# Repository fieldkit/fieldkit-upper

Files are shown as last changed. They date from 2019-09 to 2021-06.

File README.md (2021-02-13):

# FieldKit-*Upper*
The Upper board constitutes the thinky bits of the FieldKit system.
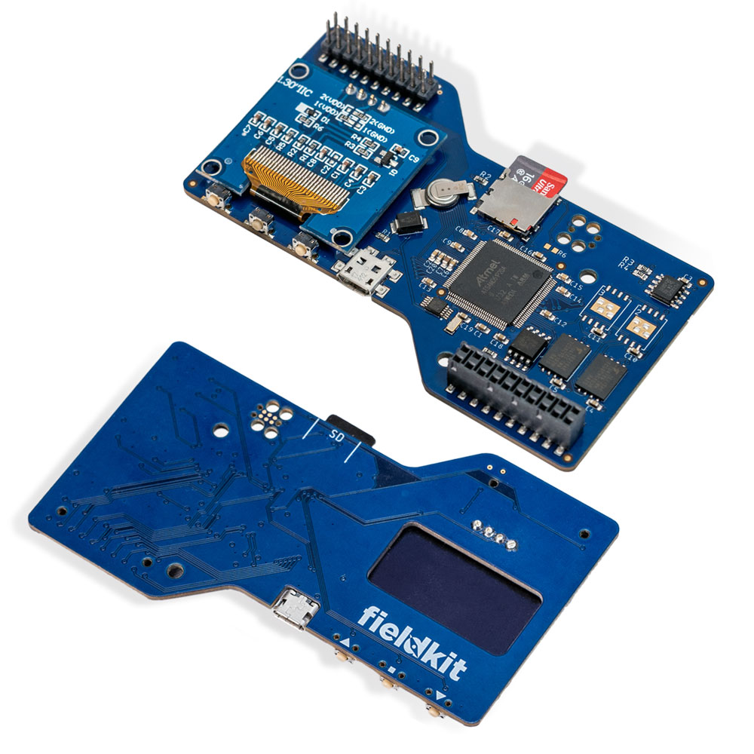
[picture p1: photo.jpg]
Photograph of Fieldkit Board


## Architecture
Every Fieldkit has at least three boards: Upper, Lower, and Module Base. Upper contains :

- The microcontroller.
- The OLED display and buttons.
- The real-time clock and its backup power supply.
- Flash memory for firmware.
- Separate NAND flash for data storage.
- The Micro-SD Card Slot.
- The USB Port.
- A temperature sensor.

## License Information

> *"In the long history of humankind (and animal kind, too) those who learned to collaborate and improvise most effectively have prevailed."*
>  --**Charles Darwin**

This hardware is released under **CERN Open Hardware License Version 2 - Permissive (CERN-OHL_P)**
Obviously, it's Distributed as-is; and no warranty is given.

---
*Upper was Designed by Bradley Gawthrop for FieldKit.*

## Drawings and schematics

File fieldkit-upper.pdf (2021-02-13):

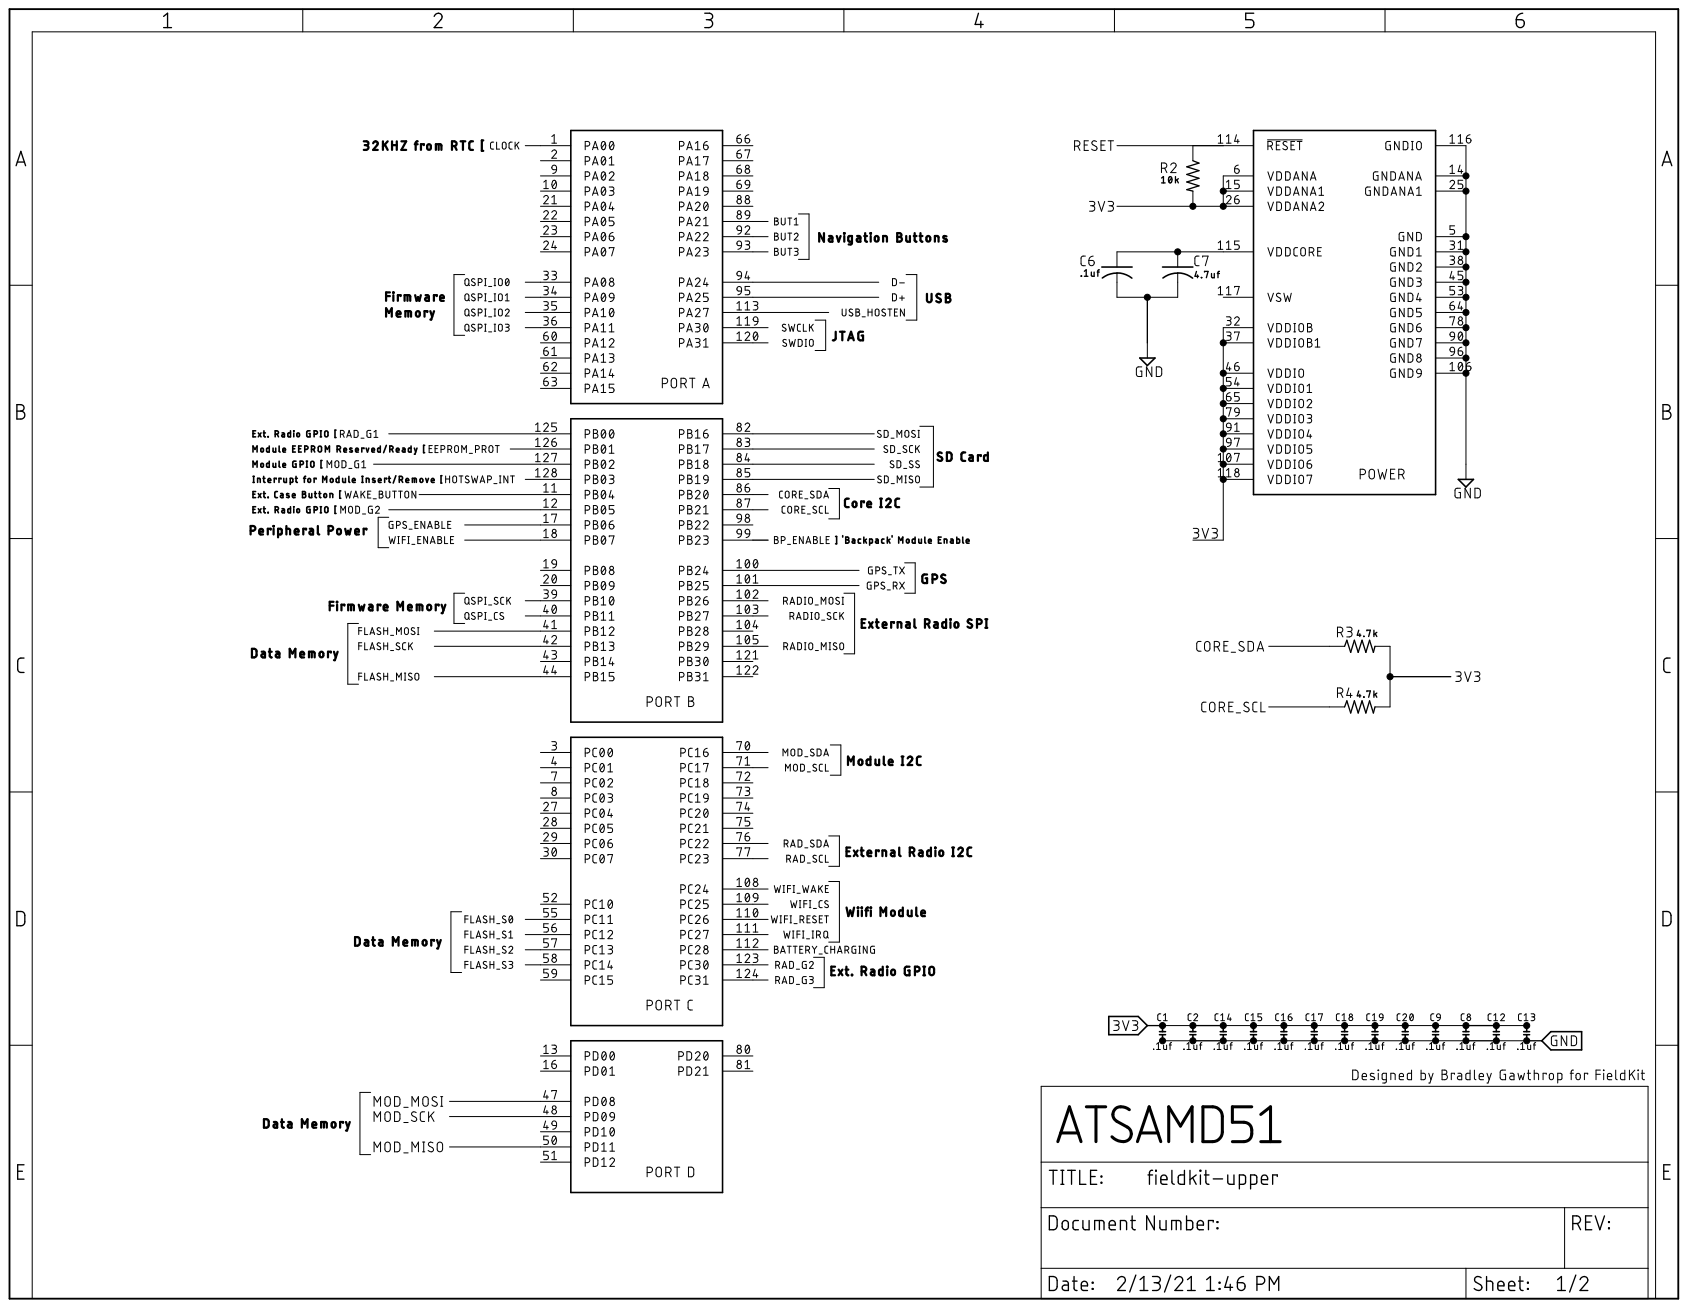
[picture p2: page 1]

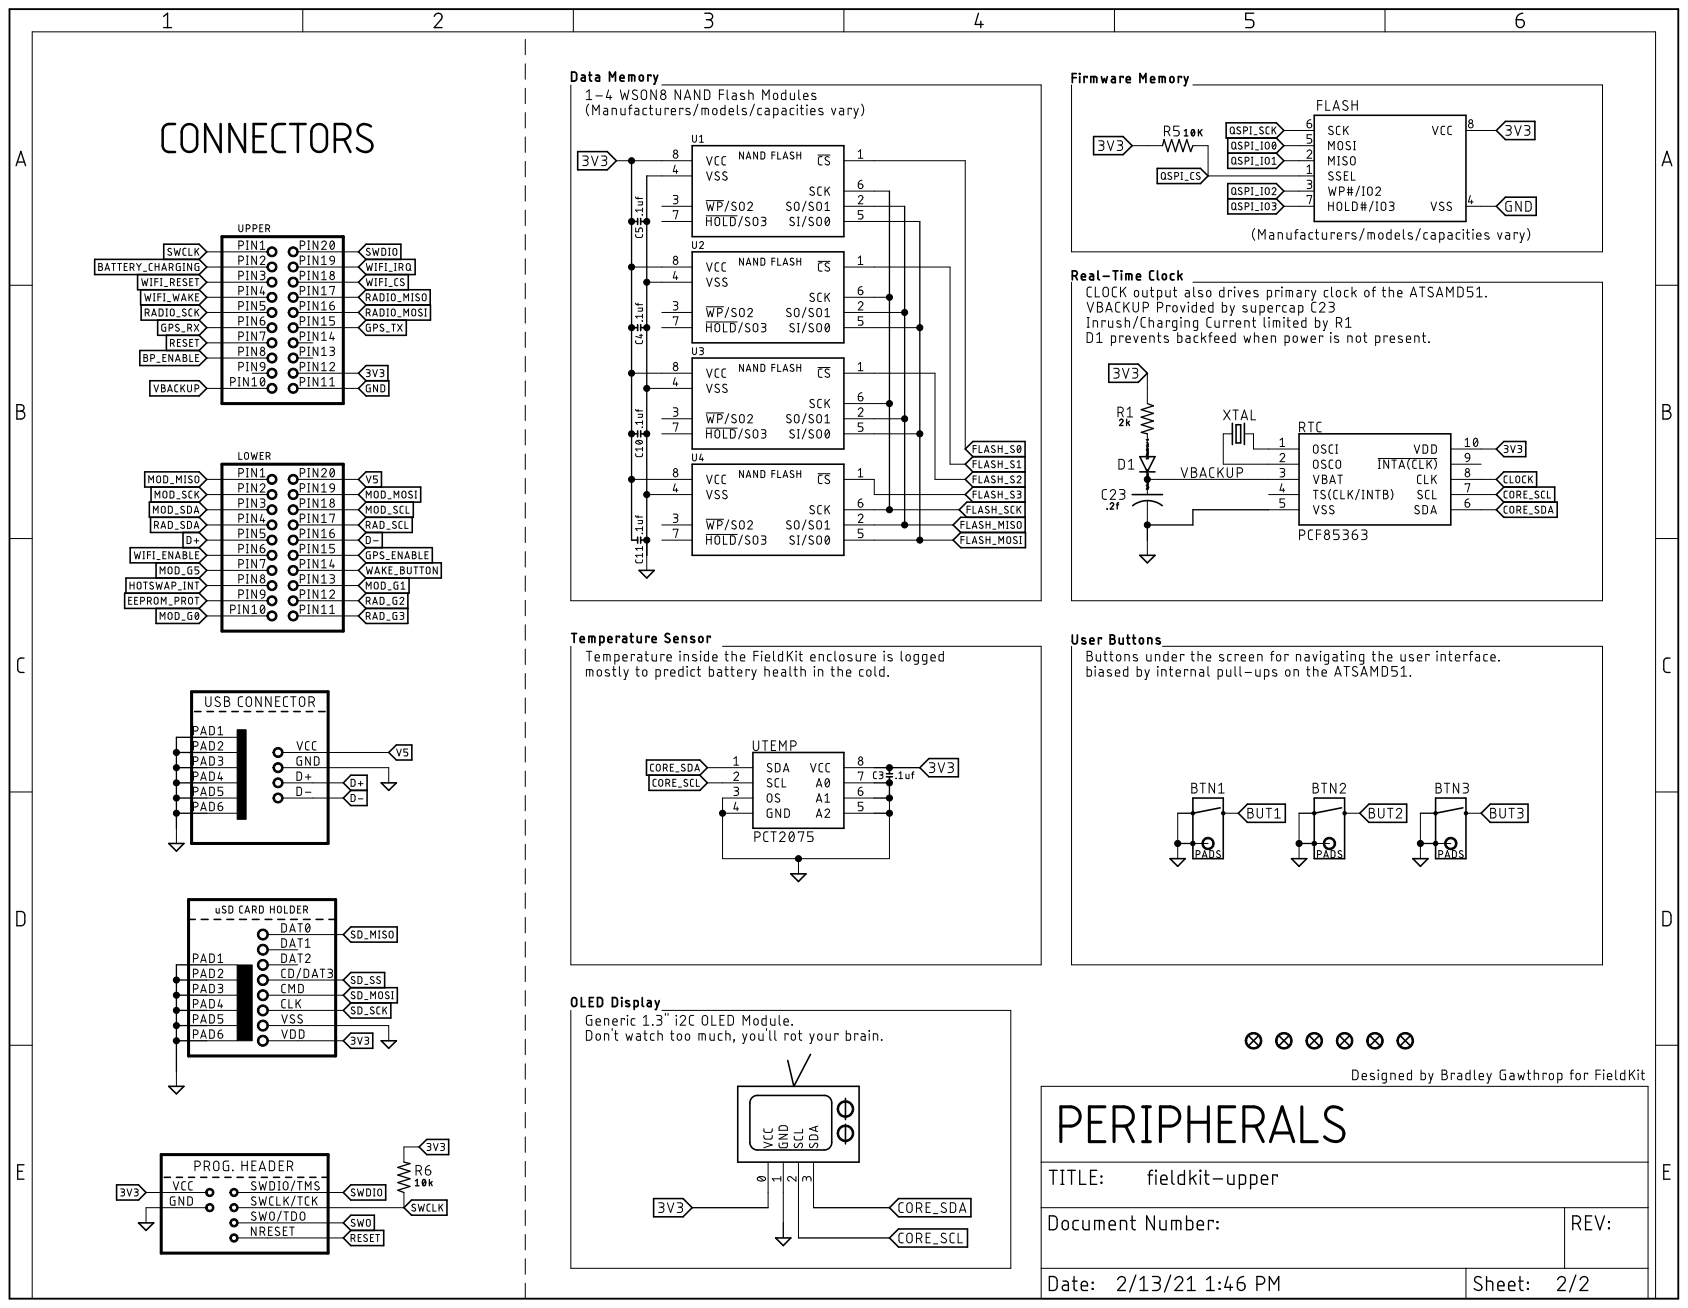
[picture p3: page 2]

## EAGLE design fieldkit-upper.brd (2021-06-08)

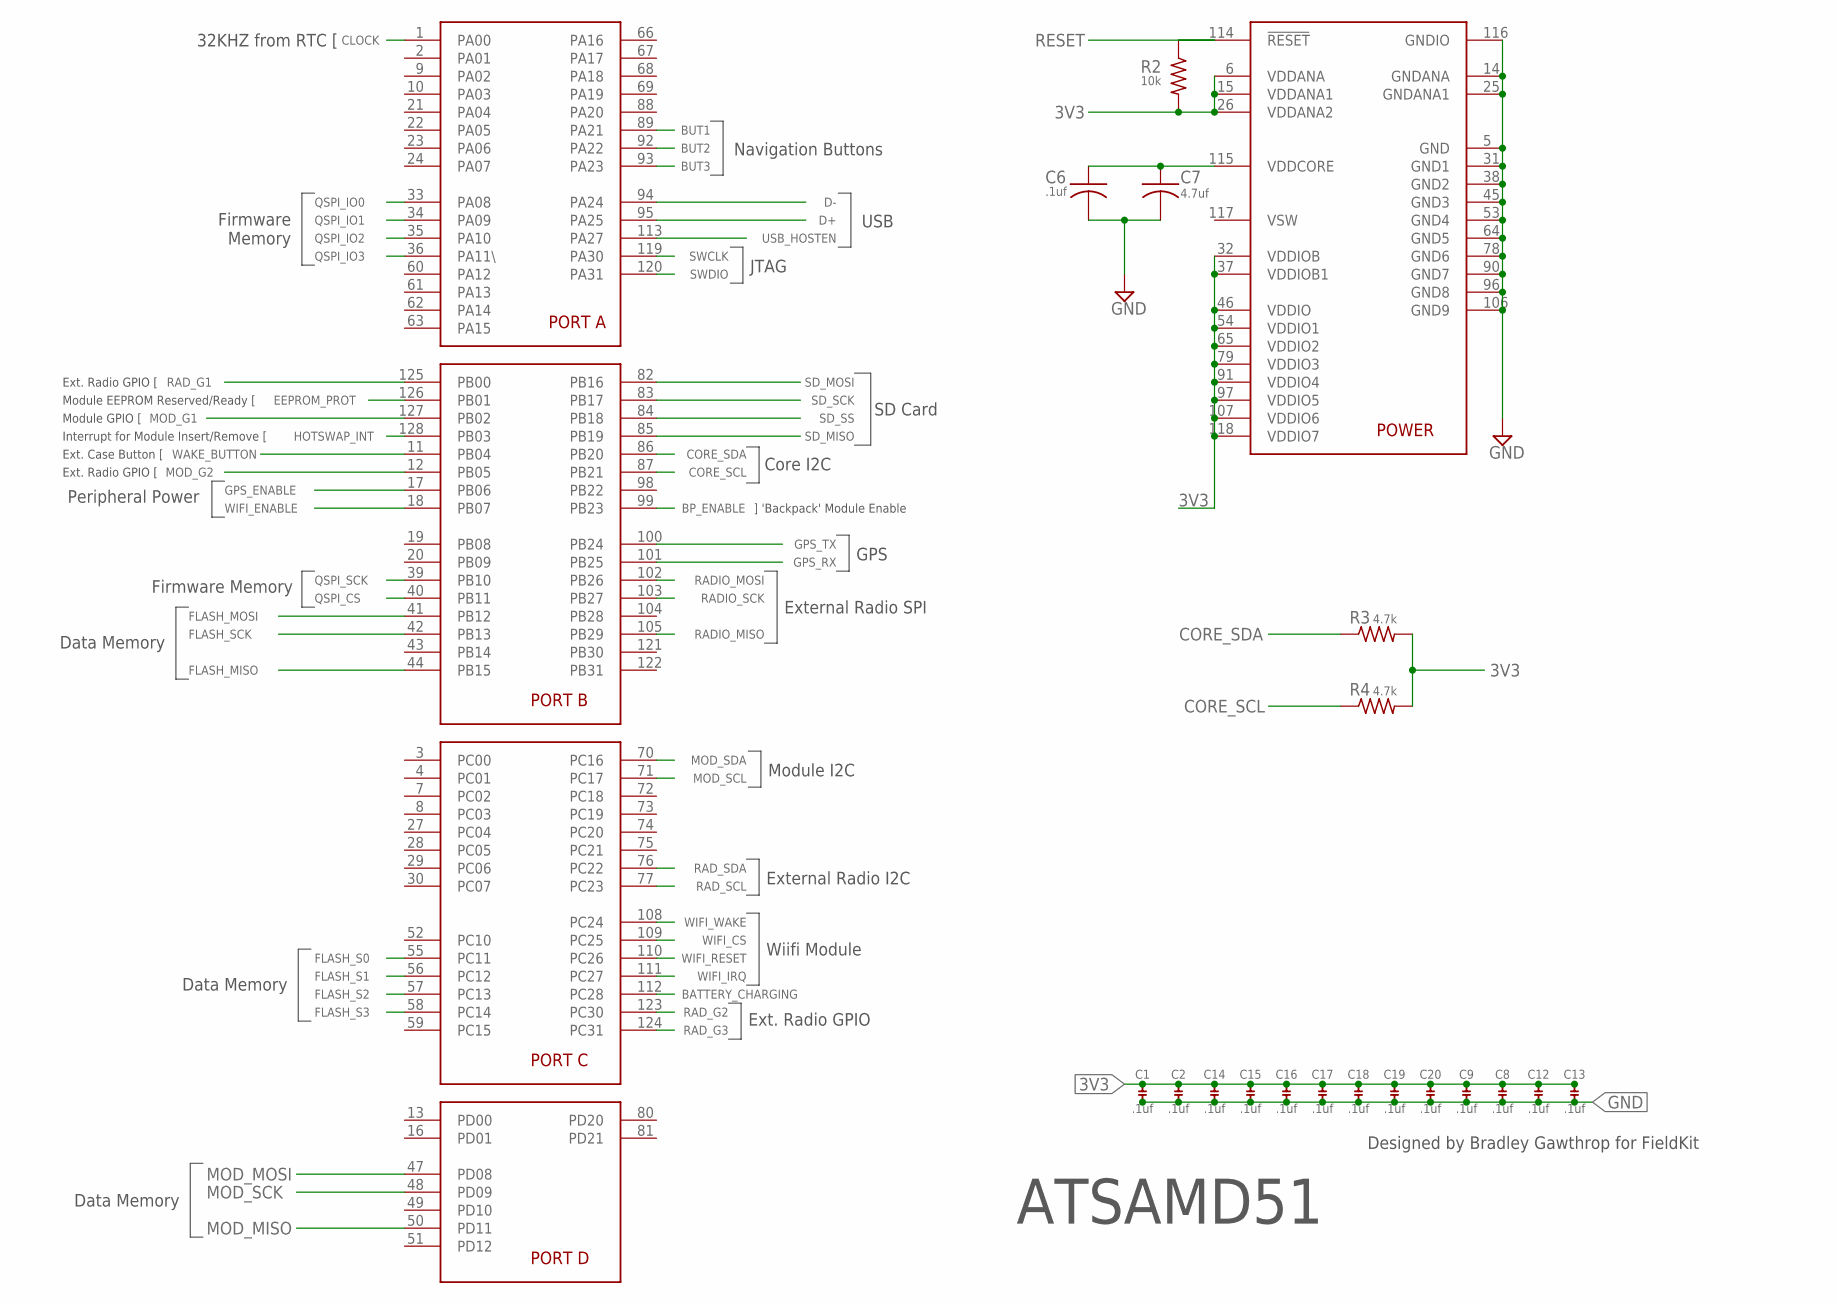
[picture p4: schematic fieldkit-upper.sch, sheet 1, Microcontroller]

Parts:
BRAIN: SAMD51PXXA; SQFP-S-14X14-128
C1, C2, C6, C8, C9, C12, C13, C14, C15, C16, C17, C18, C19, C20: .1uf; C0603K
C7: 4.7uf; C0603K
R2: 10k; R0603
R3, R4: 4.7k; R0603

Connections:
3V3: BRAIN.6 (VDDANA), BRAIN.15 (VDDANA1), BRAIN.26 (VDDANA2), BRAIN.32 (VDDIOB), BRAIN.37 (VDDIOB1), BRAIN.46 (VDDIO), BRAIN.54 (VDDIO1), BRAIN.65 (VDDIO2), BRAIN.79 (VDDIO3), BRAIN.91 (VDDIO4), BRAIN.97 (VDDIO5), BRAIN.107 (VDDIO6), BRAIN.118 (VDDIO7), C1.1, C2.1, C8.1, C9.1, C12.1, C13.1, C14.1, C15.1, C16.1, C17.1, C18.1, C19.1, C20.1, R2.2, R3.2, R4.2; also elsewhere on the board
BATTERY_CHARGING: BRAIN.112 (PC28); also elsewhere on the board
BP_ENABLE: BRAIN.99 (PB23); also elsewhere on the board
BUT1: BRAIN.89 (PA21); also elsewhere on the board
BUT2: BRAIN.92 (PA22); also elsewhere on the board
BUT3: BRAIN.93 (PA23); also elsewhere on the board
CLOCK: BRAIN.1 (PA00); also elsewhere on the board
CORE_SCL: BRAIN.87 (PB21), R4.1; also elsewhere on the board
CORE_SDA: BRAIN.86 (PB20), R3.1; also elsewhere on the board
D+: BRAIN.95 (PA25); also elsewhere on the board
D-: BRAIN.94 (PA24); also elsewhere on the board
EEPROM_PROT: BRAIN.126 (PB01); also elsewhere on the board
FLASH_MISO: BRAIN.44 (PB15); also elsewhere on the board
FLASH_MOSI: BRAIN.41 (PB12); also elsewhere on the board
FLASH_S0: BRAIN.55 (PC11); also elsewhere on the board
FLASH_S1: BRAIN.56 (PC12); also elsewhere on the board
FLASH_S2: BRAIN.57 (PC13); also elsewhere on the board
FLASH_S3: BRAIN.58 (PC14); also elsewhere on the board
FLASH_SCK: BRAIN.42 (PB13); also elsewhere on the board
GND: BRAIN.5 (GND), BRAIN.14 (GNDANA), BRAIN.25 (GNDANA1), BRAIN.31 (GND1), BRAIN.38 (GND2), BRAIN.45 (GND3), BRAIN.53 (GND4), BRAIN.64 (GND5), BRAIN.78 (GND6), BRAIN.90 (GND7), BRAIN.96 (GND8), BRAIN.106 (GND9), BRAIN.116 (GNDIO), C1.2, C2.2, C6.2, C7.2, C8.2, C9.2, C12.2, C13.2, C14.2, C15.2, C16.2, C17.2, C18.2, C19.2, C20.2; also elsewhere on the board
GPS_ENABLE: BRAIN.17 (PB06); also elsewhere on the board
GPS_RX: BRAIN.101 (PB25); also elsewhere on the board
GPS_TX: BRAIN.100 (PB24); also elsewhere on the board
HOTSWAP_INT: BRAIN.128 (PB03); also elsewhere on the board
MOD_G1: BRAIN.127 (PB02); also elsewhere on the board
MOD_G2: BRAIN.12 (PB05)
MOD_MISO: BRAIN.50 (PD11); also elsewhere on the board
MOD_MOSI: BRAIN.47 (PD08); also elsewhere on the board
MOD_SCK: BRAIN.48 (PD09); also elsewhere on the board
MOD_SCL: BRAIN.71 (PC17); also elsewhere on the board
MOD_SDA: BRAIN.70 (PC16); also elsewhere on the board
unnamed: BRAIN.115 (VDDCORE), C6.1, C7.1
QSPI_CS: BRAIN.40 (PB11); also elsewhere on the board
QSPI_IO0: BRAIN.33 (PA08); also elsewhere on the board
QSPI_IO1: BRAIN.34 (PA09); also elsewhere on the board
QSPI_IO2: BRAIN.35 (PA10); also elsewhere on the board
QSPI_IO3: BRAIN.36 (PA11\); also elsewhere on the board
QSPI_SCK: BRAIN.39 (PB10); also elsewhere on the board
RADIO_MISO: BRAIN.105 (PB29); also elsewhere on the board
RADIO_MOSI: BRAIN.102 (PB26); also elsewhere on the board
RADIO_SCK: BRAIN.103 (PB27); also elsewhere on the board
RAD_G1: BRAIN.125 (PB00); also elsewhere on the board
RAD_G2: BRAIN.123 (PC30); also elsewhere on the board
RAD_G3: BRAIN.124 (PC31); also elsewhere on the board
RAD_SCL: BRAIN.77 (PC23); also elsewhere on the board
RAD_SDA: BRAIN.76 (PC22); also elsewhere on the board
RESET: BRAIN.114 (!RESET), R2.1; also elsewhere on the board
SD_MISO: BRAIN.85 (PB19); also elsewhere on the board
SD_MOSI: BRAIN.82 (PB16); also elsewhere on the board
SD_SCK: BRAIN.83 (PB17); also elsewhere on the board
SD_SS: BRAIN.84 (PB18); also elsewhere on the board
SWCLK: BRAIN.119 (PA30); also elsewhere on the board
SWDIO: BRAIN.120 (PA31); also elsewhere on the board
USB_HOSTEN: BRAIN.113 (PA27)
WAKE_BUTTON: BRAIN.11 (PB04); also elsewhere on the board
WIFI_CS: BRAIN.109 (PC25); also elsewhere on the board
WIFI_ENABLE: BRAIN.18 (PB07); also elsewhere on the board
WIFI_IRQ: BRAIN.111 (PC27); also elsewhere on the board
WIFI_RESET: BRAIN.110 (PC26); also elsewhere on the board
WIFI_WAKE: BRAIN.108 (PC24); also elsewhere on the board

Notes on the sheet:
Navigation Buttons
32KHZ from RTC [
Firmware Memory
USB
JTAG
SD Card
Core I2C
External Radio SPI
] 'Backpack' Module Enable
Data Memory
Firmware Memory
Module I2C
External Radio I2C
Interrupt for Module Insert/Remove [
GPS
Ext. Radio GPIO [
Module EEPROM Reserved/Ready [
Module GPIO [
Ext. Case Button [
Peripheral Power
Wiifi Module
Ext. Radio GPIO
ATSAMD51
Designed by Bradley Gawthrop for FieldKit

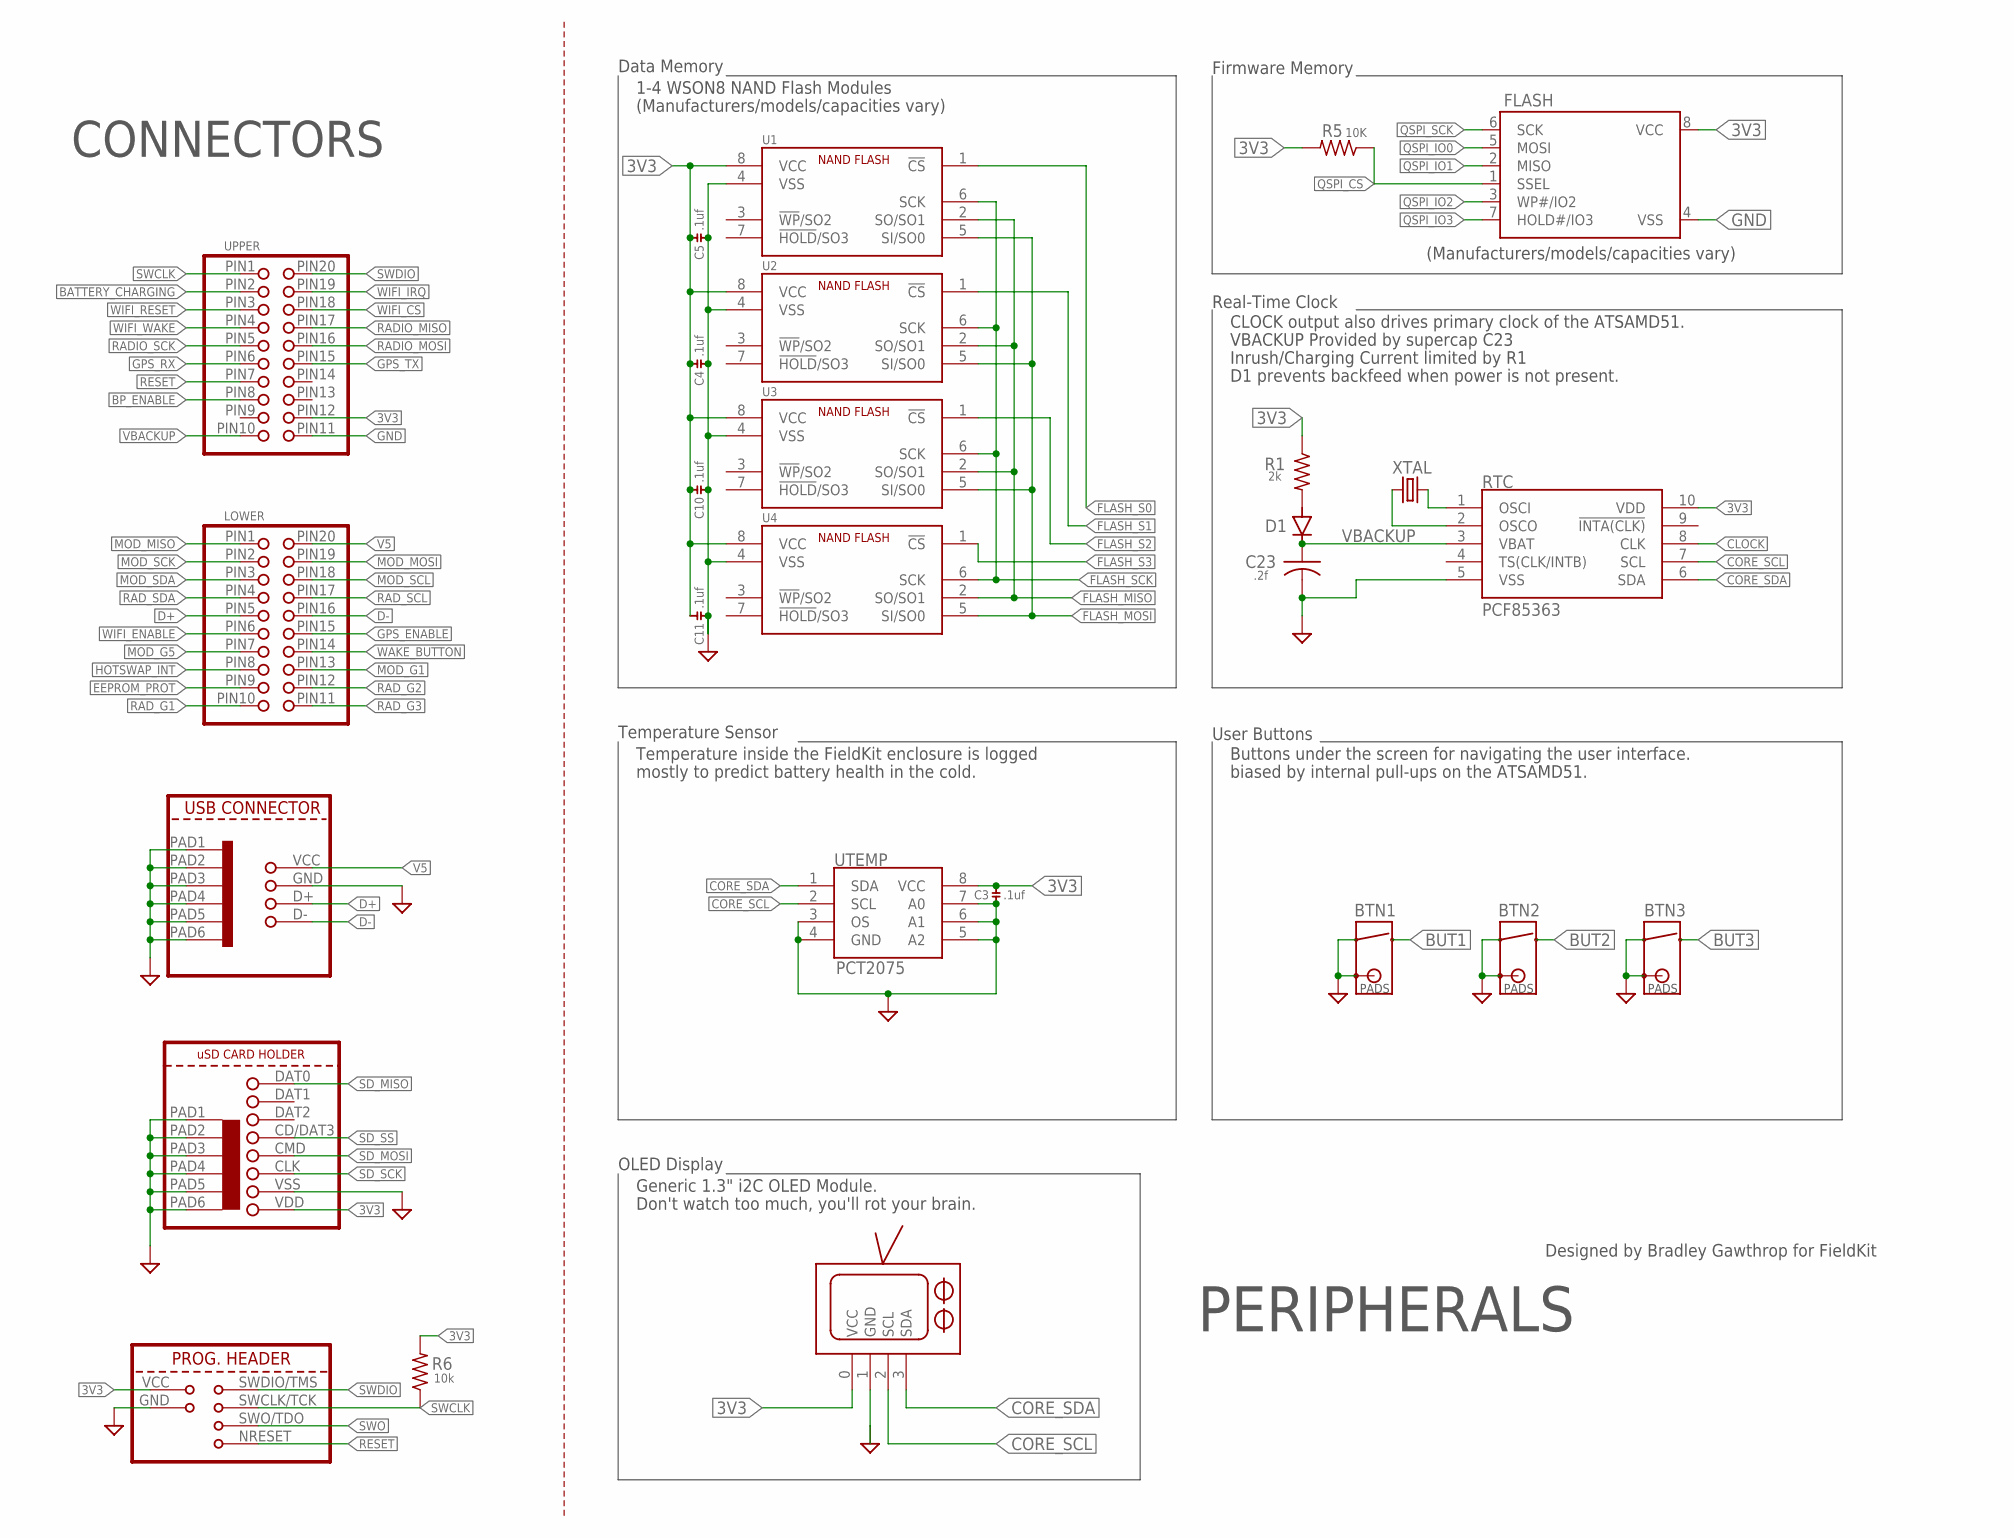
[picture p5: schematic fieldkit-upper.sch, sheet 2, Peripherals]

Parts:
BTN1, BTN2, BTN3: SKRTLAE010
C3, C4, C5, C10, C11: .1uf; C0603K
C23: .2f; SUPERCAP
D1: VS-10BQ015HM3/5BT; SMB
FLASH: SPIFLASH_SOIC8208MIL; SOIC8_208MIL
J1: TAG-CONNECT; TC2030-IDC
LOWER: MOLEX-15-91-2200F; 20PH-F
R1: 2k; R0603
R5: 10K; R0603
R6: 10k; R0603
RTC: PCF85363ATT; SOP50P490X110-10
SCREEN: SCREEN
SD: DM3D-SF
U1, U2, U3, U4: TC58CVG1S3HRAIG; WSON8
UPPER: MOLEX-15-91-2200F; 20PH-F
USB: MOLEX-47491-0001; MOELX-47491-0001
UTEMP: PCT2075; SO8
XTAL: ABS07W

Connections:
3V3: C3.1, C4.1, C5.1, C10.1, C11.1, FLASH.8 (VCC), J1.VCC, R1.1, R5.2, R6.2, RTC.10 (VDD), SCREEN.0 (VCC), SD.VDD, U1.8 (VCC), U2.8 (VCC), U3.8 (VCC), U4.8 (VCC), UPPER.PIN12, UTEMP.8 (VCC); also elsewhere on the board
BATTERY_CHARGING: UPPER.PIN2; also elsewhere on the board
BP_ENABLE: UPPER.PIN8; also elsewhere on the board
BUT1: BTN1.B (2); also elsewhere on the board
BUT2: BTN2.B (2); also elsewhere on the board
BUT3: BTN3.B (2); also elsewhere on the board
CLOCK: RTC.8 (CLK); also elsewhere on the board
CORE_SCL: RTC.7 (SCL), SCREEN.2 (SCL), UTEMP.2 (SCL); also elsewhere on the board
CORE_SDA: RTC.6 (SDA), SCREEN.3 (SDA), UTEMP.1 (SDA); also elsewhere on the board
D+: LOWER.PIN5, USB.D+; also elsewhere on the board
D-: LOWER.PIN16, USB.D-; also elsewhere on the board
EEPROM_PROT: LOWER.PIN9; also elsewhere on the board
FLASH_MISO: U1.2 (SO/SO1), U2.2 (SO/SO1), U3.2 (SO/SO1), U4.2 (SO/SO1); also elsewhere on the board
FLASH_MOSI: U1.5 (SI/SO0), U2.5 (SI/SO0), U3.5 (SI/SO0), U4.5 (SI/SO0); also elsewhere on the board
FLASH_S0: U1.1 (!CS); also elsewhere on the board
FLASH_S1: U2.1 (!CS); also elsewhere on the board
FLASH_S2: U3.1 (!CS); also elsewhere on the board
FLASH_S3: U4.1 (!CS); also elsewhere on the board
FLASH_SCK: U1.6 (SCK), U2.6 (SCK), U3.6 (SCK), U4.6 (SCK); also elsewhere on the board
GND: BTN1.A (1), BTN1.A2 (1), BTN1.TAB (PADS), BTN1.TAB2 (PADS), BTN2.A (1), BTN2.A2 (1), BTN2.TAB (PADS), BTN2.TAB2 (PADS), BTN3.A (1), BTN3.A2 (1), BTN3.TAB (PADS), BTN3.TAB2 (PADS), C3.2, C4.2, C5.2, C10.2, C11.2, C23.-, FLASH.4 (VSS), J1.GND, RTC.5 (VSS), SCREEN.1 (GND), SD.PAD1, SD.PAD2, SD.PAD3, SD.PAD4, SD.PAD5, SD.PAD6, SD.VSS, U1.4 (VSS), U2.4 (VSS), U3.4 (VSS), U4.4 (VSS), UPPER.PIN11, USB.GND, USB.PAD1, USB.PAD2, USB.PAD3, USB.PAD4, USB.PAD5, USB.PAD6, UTEMP.3 (OS), UTEMP.4 (GND), UTEMP.5 (A2), UTEMP.6 (A1), UTEMP.7 (A0); also elsewhere on the board
GPS_ENABLE: LOWER.PIN15; also elsewhere on the board
GPS_RX: UPPER.PIN6; also elsewhere on the board
GPS_TX: UPPER.PIN15; also elsewhere on the board
HOTSWAP_INT: LOWER.PIN8; also elsewhere on the board
MOD_G1: LOWER.PIN13; also elsewhere on the board
MOD_G5: LOWER.PIN7
MOD_MISO: LOWER.PIN1; also elsewhere on the board
MOD_MOSI: LOWER.PIN19; also elsewhere on the board
MOD_SCK: LOWER.PIN2; also elsewhere on the board
MOD_SCL: LOWER.PIN18; also elsewhere on the board
MOD_SDA: LOWER.PIN3; also elsewhere on the board
unnamed: D1.A, R1.2
unnamed: RTC.1 (OSCI), XTAL.P$2 (2)
unnamed: RTC.2 (OSCO), XTAL.P$1 (1)
QSPI_CS: FLASH.1 (SSEL), R5.1; also elsewhere on the board
QSPI_IO0: FLASH.5 (MOSI); also elsewhere on the board
QSPI_IO1: FLASH.2 (MISO); also elsewhere on the board
QSPI_IO2: FLASH.3 (WP#/IO2); also elsewhere on the board
QSPI_IO3: FLASH.7 (HOLD#/IO3); also elsewhere on the board
QSPI_SCK: FLASH.6 (SCK); also elsewhere on the board
RADIO_MISO: UPPER.PIN17; also elsewhere on the board
RADIO_MOSI: UPPER.PIN16; also elsewhere on the board
RADIO_SCK: UPPER.PIN5; also elsewhere on the board
RAD_G1: LOWER.PIN10; also elsewhere on the board
RAD_G2: LOWER.PIN12; also elsewhere on the board
RAD_G3: LOWER.PIN11; also elsewhere on the board
RAD_SCL: LOWER.PIN17; also elsewhere on the board
RAD_SDA: LOWER.PIN4; also elsewhere on the board
RESET: J1.NRESET (RESET), UPPER.PIN7; also elsewhere on the board
SD_MISO: SD.DAT0; also elsewhere on the board
SD_MOSI: SD.CMD; also elsewhere on the board
SD_SCK: SD.CLK; also elsewhere on the board
SD_SS: SD.CD/DAT3 (DAT3); also elsewhere on the board
SWCLK: J1.SWCLK/TCK (SWCLK), R6.1, UPPER.PIN1; also elsewhere on the board
SWDIO: J1.SWDIO/TMS (SWDIO), UPPER.PIN20; also elsewhere on the board
SWO: J1.SWO/TDO (SWO)
V5: LOWER.PIN20, USB.VCC (VBUS)
VBACKUP: C23.+, D1.C, RTC.3 (VBAT), UPPER.PIN10
WAKE_BUTTON: LOWER.PIN14; also elsewhere on the board
WIFI_CS: UPPER.PIN18; also elsewhere on the board
WIFI_ENABLE: LOWER.PIN6; also elsewhere on the board
WIFI_IRQ: UPPER.PIN19; also elsewhere on the board
WIFI_RESET: UPPER.PIN3; also elsewhere on the board
WIFI_WAKE: UPPER.PIN4; also elsewhere on the board

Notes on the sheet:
.2f
CONNECTORS
Data Memory
1-4 WSON8 NAND Flash Modules
(Manufacturers/models/capacities vary)
Firmware Memory
Real-Time Clock
CLOCK output also drives primary clock of the ATSAMD51.
VBACKUP Provided by supercap C23
Inrush/Charging Current limited by R1
D1 prevents backfeed when power is not present.
RTC
PCF85363
Temperature Sensor
Temperature inside the FieldKit enclosure is logged
mostly to predict battery health in the cold.
User Buttons
Buttons under the screen for navigating the user interface.
biased by internal pull-ups on the ATSAMD51.
OLED Display
Generic 1.3" i2C OLED Module.
Don't watch too much, you'll rot your brain.
PERIPHERALS
Designed by Bradley Gawthrop for FieldKit

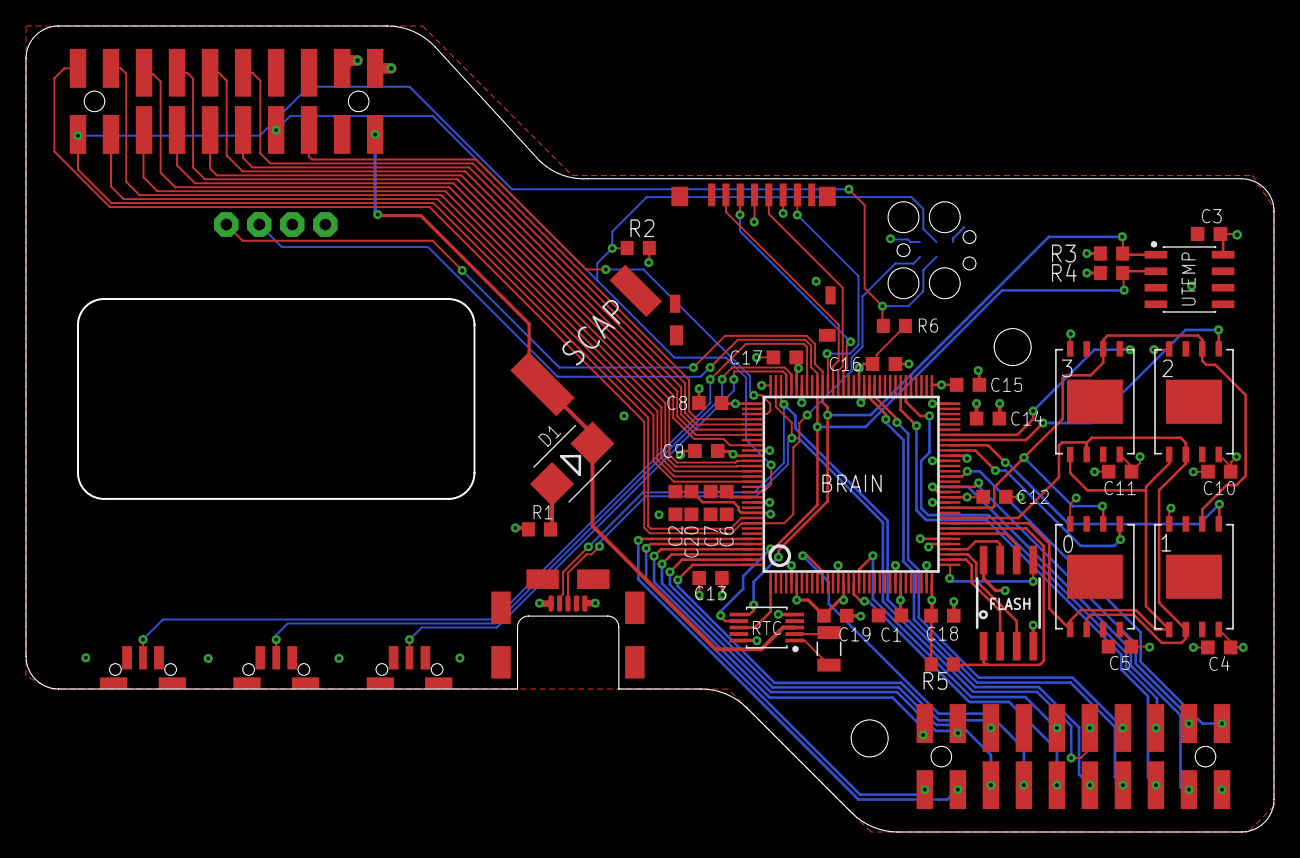
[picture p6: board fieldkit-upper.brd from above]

Board: 4 copper layers, 96.0 x 62.0 mm, 46 parts (1 on the bottom side), 63 nets.

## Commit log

2019-05-23 Initial Lash-Up.
    [darwin-integrated.brd, darwin-integrated.sch]
2019-05-23 DRC related cleanup.
    [darwin-integrated.brd]
2019-05-23 Silk cleanup and other housecleaning.
    [darwin-integrated.brd, darwin-integrated.sch]
2019-05-23 Added screen contacts
    [darwin-integrated.brd, darwin-integrated.sch]
2019-05-23 Routing Tweaks
    [darwin-integrated.brd]
2019-05-23 Minor cleanup, CAM files created.
    [copper_bottom_l4.gbr, copper_inner_l2.gbr, copper_inner_l3.gbr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]
2019-06-13 Corrected VDDCORE and VSW errors.
    [darwin-integrated.brd, darwin-integrated.sch]
2019-06-13 Added pullup resistor for QSPI Flash chip select.
    [darwin-integrated.brd, darwin-integrated.sch]
2019-06-13 Moved SD card, USB, and Temp sensor posistions for better cable access. Expanded screen window by 2MM.
    [darwin-integrated.brd]
2019-06-14 Fixed Memory footprints. CAM output for TA2. Reorganized CAM files.
    [darwin-integrated.brd, darwin-integrated.sch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]
2019-06-14 Whoops! Fixed a DRC errors. Re-CAM'd as TA2b.
    [darwin-integrated.brd]
2019-07-17 Fixed SD Power Disconnect.
    [darwin-integrated.brd, darwin-integrated.sch]
2019-09-03 Panelized. PA1.
    [darwin-integrated-panel.brd, darwin-integrated.brd, darwin-integrated.sch]
2020-01-16 Moved USB connector location, replaced buttons, tidied decoupling caps and routing.
    [darwin-integrated-panel.brd, darwin-upper-panel.brd, darwin-upper.brd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]
2020-02-11 Added Tag-Connect header.
    [darwin-upper-panel.brd, darwin-upper.brd, darwin-upper.sch]
2020-05-01 Schematic cleanup and add PDF.
    [darwin-upper.brd, darwin-upper.sch]
2021-02-13 Schematic readability overhaul, repo look & feel.
    [darwin-upper-panel.brd, fieldkit-upper.brd, fieldkit-upper.sch]
2021-02-13 Minor schematic style changes.
    [fieldkit-upper.sch]
2021-06-08 Routing cleanup, pin nomenclature fixes.
    [fieldkit-upper.brd, fieldkit-upper.sch]
